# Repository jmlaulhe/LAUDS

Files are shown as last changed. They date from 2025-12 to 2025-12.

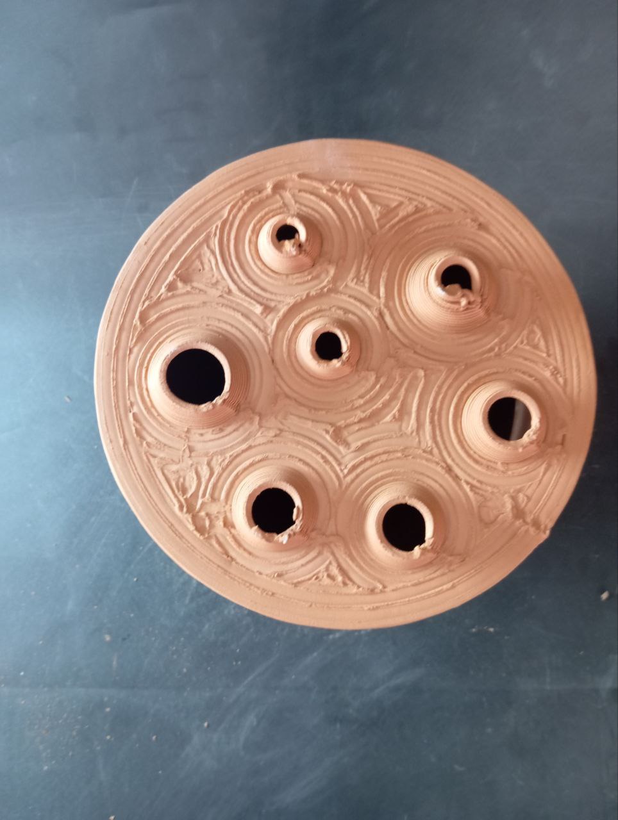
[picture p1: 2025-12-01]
04_hardware/02_sources_media/img/photo_49_2025-10-27_17-47-01.jpg

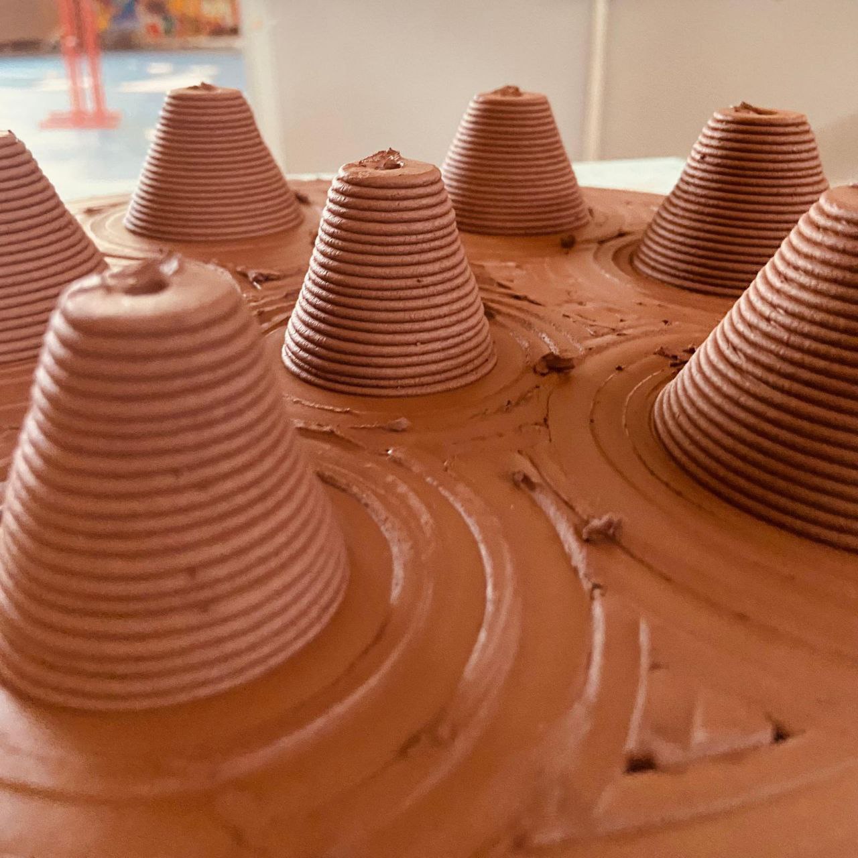
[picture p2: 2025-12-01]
04_hardware/02_sources_media/img/photo_51_2025-10-27_17-47-01.jpg

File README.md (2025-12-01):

# Hacking a plant pot into a vermicomposter

We provide here a guide to hack a plant pot and transform it into a vermicomposter,
a modular system that can be adapted to both vertical and horizontal configurations.

You can also cite and access the project files at:

<https://room11.es/projects/LAUDS-RgitA/>

<https://gardenatlas.net/garden/jardin-acondicionado-1/?filter=2>

## Vision: Vermicomposter for Mediterranean Climates.

We aim to share and improve a functional vermicomposter designed for outdoor environments in Mediterranean climates,
which can be adapted to both vertical and horizontal settings in urban contexts.
The documentation is intended to facilitate the adaptation of the design to different local conditions and to materials that are readily available.

## Metadata

-   development stage: prototype, first stable version of the project, tests ongoing
-   license: CERN-OHL-W for hardware process definitions (content of the 04_hardware folder),  CC BY-SA 4.0 for documentation;.
-   subject area/type of hardware: (vertical) farming
-   prerequisite: documentation made for future contributors

## Main outputs

-   Parametric design files for creating your own vermicomposter by hacking a ceramic plant pot

-   Pictures and guides for adapting the process to different contexts and needs

## Problem description

The lack of fertile soil is common in urban contexts, and its regeneration requires multiple actions.
Vermicomposting is one of the simplest ways to integrate our daily environments into this regenerative process.
Plant pots represent a traditional, widely accepted technology that enhances vermicomposting practices:
they are aesthetically compatible and serve as effective hygrothermal regulators.

## Contributing

Please feel welcome to use the Github issues to flag errors and tell us what you think.
You may also contact the maintainer per email (see contributors section).

## Project history and roadmap

The project builds upon the experience of Gardens in the Air (Nomad Garden, 2021–2023),
a vertical garden implemented on the façade of AES Nuestra Señora de la Candelaria in Seville,
irrigated with condensate water recovered from air-conditioning systems.

The LAUDS framework provided an opportunity to address several constraints
through maker methodologies, participatory prototyping, and open-source design processes.
During the early stages, community feedback from AES Candelaria encouraged us to rethink
the initial vertical-garden concept and explore the integration of the organic carbon cycle
alongside the existing water cycle in the condensate system.

From this reflection emerged a new hypothesis: it is possible to produce fertile soil
within the built environment by embedding vermicomposting systems into both vertical and horizontal structures.
The resulting design — Redesigning Gardens in the Air — aimed to close local material loops
by transforming daily organic waste into humus and reintegrating it into urban cultivation.

The technical challenge lies in adapting this natural process to outdoor, façade-oriented environments,
using bioclimatic ceramic containers capable of buffering temperature fluctuations
through evaporative cooling powered by recovered condensate water.

Next steps:

- Ensure compatibility with other parametric design software

- Open the project for feedback and external contributions

- Test the system in different contexts (urban orchards, community gardens, etc.)

Long term:

-   build a network of vermicomposter initiatives to enable self-managed development of the project

### Related projects

[to be completed]

## Funding

This was developed inside the LAUDS Factories call, facing the challenge "Greening Urban Spaces: Innovate Vertical Farming Systems from Local Waste Streams".

[LAUDS Local Accessible Urban Digital Sustainable Factories](https://www.lauds.eu) is a Horizon Europe research and innovation action - Co-funded by the European Union, 2024-2026, GA 101135986.

## Main contributors:

-   T11- Creative Space
-   Nomad Garden SL
-   Adriano Jiménez
-   Fab Lab Sevilla
-   AES Nuestra Señora de la Candelaria
-   Ecosistema 41

### work culture 

-   [guidelines](01_community/01_community_guidelines.md)
-   [Code of conduct](01_community/02_coc.md)

## Documentation structure

This readme contains the first level of information.
in 
- 01_community are saved our detailed documentation about the community practices
- 02_project_history you will find information about past decisions in the project
- 03_specification_concept you will find high level analysis of the hardware design like the list or requirements and user analysis
- 04_hardware you will find information to build the hardware
- 05_user_guides you will find information to use and maintain/dispose the hardware

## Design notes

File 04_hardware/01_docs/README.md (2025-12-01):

PDF with the main parts of the vermicomposter system to be placed in exteriors

- Shell assembly: recovering the properties of mashrabiya, an Islamic solution for Mediterranean window openings.
- Vermicomposter: parts of the hacking of a plant pot in a vermicomposter.

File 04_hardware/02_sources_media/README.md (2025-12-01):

### Parametric design

Made in Rhinoceros parametric plug-in, Grasshopper.

- Ceramic /PLA lid (Parameters: dimension of rim, geometry, nozzle)
- Trays for the vermicomposter (Parameters: height of trays, dimensions of plant pots, holes for worms)

### CAD drawings

DXF made in AutoCAD for the shell of the mashrabiya.

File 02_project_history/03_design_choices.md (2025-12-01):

**Material Sourcing and Selection**

Primary structural element: traditional fired ceramic pots (15 L) from regional potteries in the Guadalquivir valley. Pots are selected for porosity, dimensional standardisation, and existing supply chains.
Hack components: bespoke lids, capillary distributors, internal trays and seed templates produced by digital fabrication (3D printing in ceramic composite or PLA biocomposite).
Biological input: Eisenia fetida worm communities and local organic residues.

**Design Adaptation and Digital Fabrication**

Parametric design (Rhino + Grasshopper) generates adaptable geometries for retrofitting standard pot sizes. Designs produce: (a) lid inserts that match pot rims; (b) tray geometries that fit pot interior contours; (c) capillary channel patterns for condensate distribution.
Additive fabrication produces the hack components: 3D-printed lids (ceramic composite or clay in lab trials), internal trays (PLA/biocomposite), and small fixtures for anchorage to mashrabiya panels. Where ceramic printing is not feasible, components are printed in PLA biocomposite and later transitioned to fired ceramic versions via collaboration with local kilns.

**Mechanical and Hydraulic Integration (Hacking Traditional Pots)**

The hack operation consists of: (a) preparing the pot rim and interior to receive inserts (minor drilling, chamfering, or application of sealing gaskets where necessary); (b) fitting the custom lid that captures condensate and distributes it across the pot surface through microchannels; (c) installing stackable internal trays that create layered habitats, drainage paths, and aeration.
All modifications are reversible and preserve the integrity of the traditional pot, enabling reusability or return to standard horticultural use.

**Community Assembly and Calibration**

Hacking sessions are organised as participatory workshops with AES Candelaria students and local potters. These sessions include instruction on fitting inserts, maintenance protocols, and simple diagnostic checks (moisture, ventilation, leachate collection).
Performance calibration (moisture rates, worm activity, thermal buffering) is measured in situ and iteratively used to refine both the parametric designs and the installation procedure.

**Closed-Loop Testing and Material Trials**

Produced humus is applied to pot substrates and the association’s urban plots to close the material loop.
Parallel experiments at Fab Lab Sevilla test humus–clay mixtures for future fired components (seed trays, degradable supports), ensuring that any new ceramic parts remain compatible with the traditional pottery supply chain.

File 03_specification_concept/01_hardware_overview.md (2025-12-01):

## foreseen cost (money and time)
The required cost is very low. A 15-liter ceramic pot can range between €15–30 depending on the country.

There is also a non-recurring cost that is useful for activating our vermicomposter: the initial worm colony and some good-quality soil, so that the worms do not suffer when settling in. For around €20 you can obtain a handful of worms (about 500 individuals), and if you wish to purchase humus — which can also be used for your garden — a 40-liter bag costs approximately €20.

Time, however, is a determining factor. At the beginning, you will need to check the vermicomposter almost daily in order to adjust it. Once it is functioning properly, you should tend to it two or three times per week. If there are more extreme temperatures — either hot or cold — you should check it almost every day.

## requirements

## constrains

## capability

## use cases and application

## reuse possibilities

## architectural structure

## Software/firmware architecture

## electrical design architecture

## Component lifetime

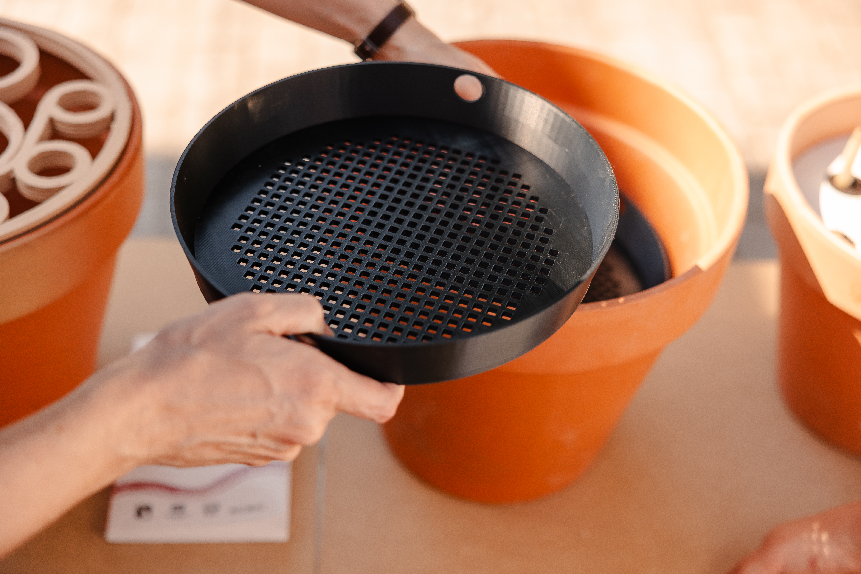
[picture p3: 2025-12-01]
04_hardware/02_sources_media/img/GARDEN ATLAS-AES CANDELARIA-307.jpg

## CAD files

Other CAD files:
04_hardware/02_sources_media/Shell_laser.dxf

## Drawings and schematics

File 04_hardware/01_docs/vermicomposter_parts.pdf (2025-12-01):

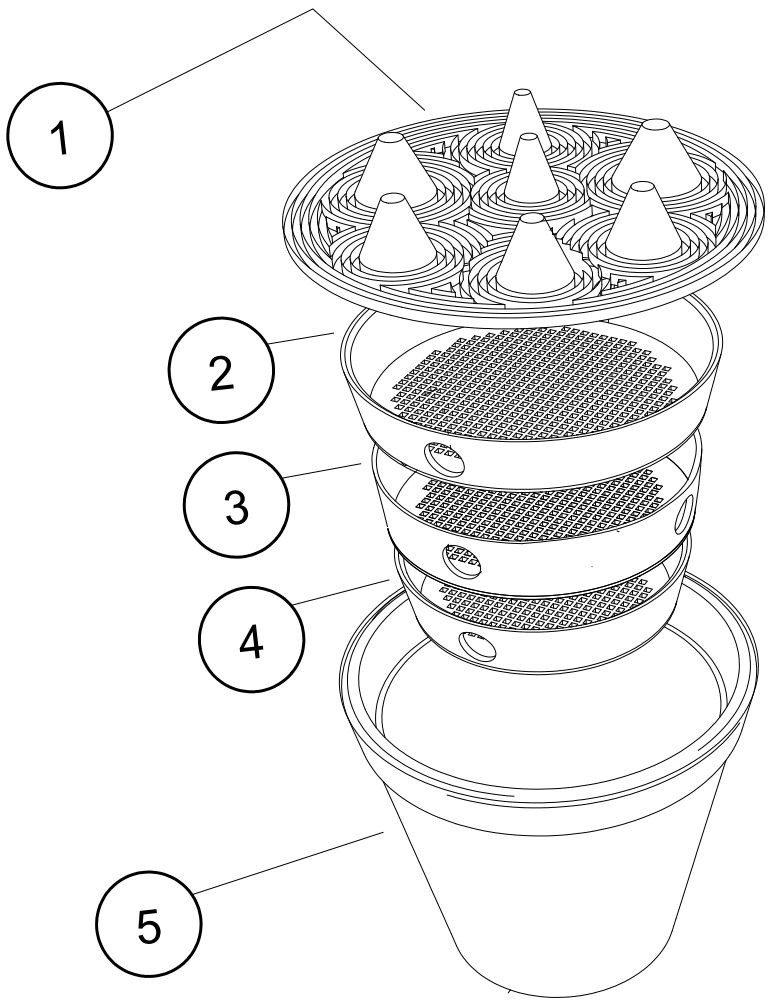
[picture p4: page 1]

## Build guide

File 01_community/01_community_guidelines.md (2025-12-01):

Local suppliers. In our instance, the local potteries (Guadalquivir valley): suppliers of standard ceramic pots and partners for potential fired retrofit parts.

Testing community and space. In our instance, AES Nuestra Señora de la Candelaria: assembly, monitoring and educational partner.

Techincial providers. In our instance, Fab Lab Sevilla & Maker Association: fabrication and prototyping partners for hack components.

Design and coordination. In our instance, Nomad Garden & T11: design coordination, workshop facilitation, and documentation.

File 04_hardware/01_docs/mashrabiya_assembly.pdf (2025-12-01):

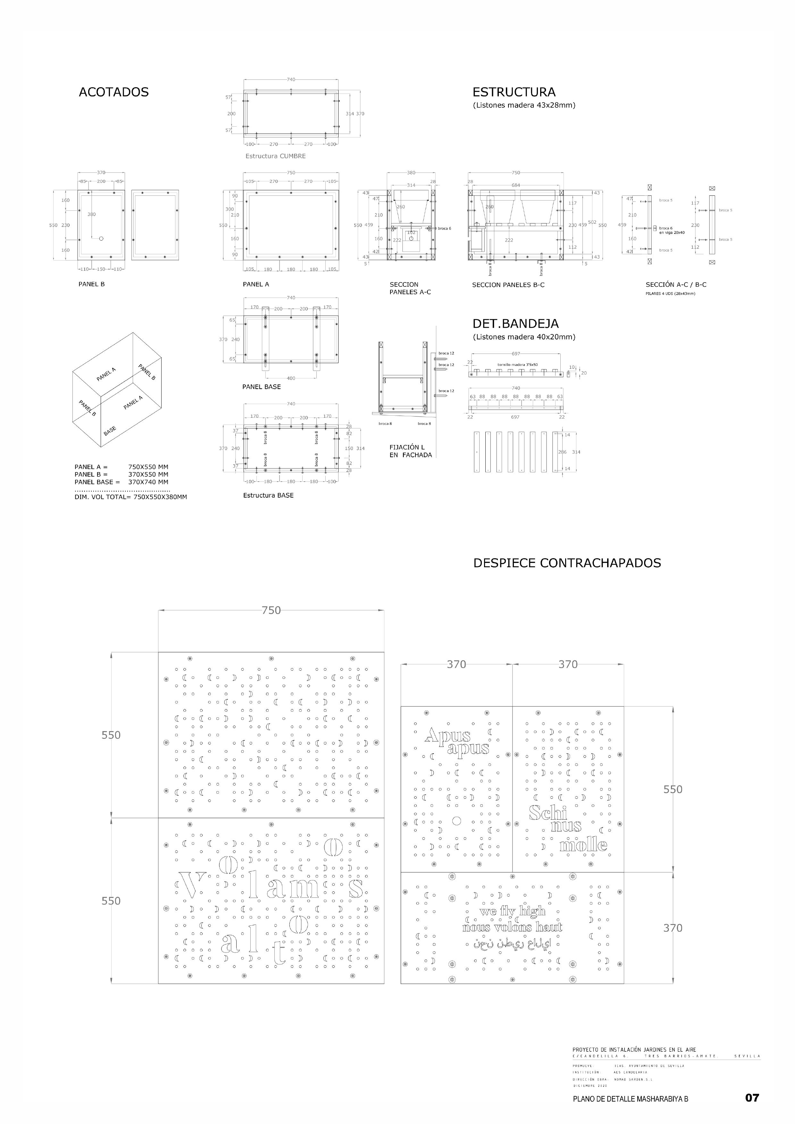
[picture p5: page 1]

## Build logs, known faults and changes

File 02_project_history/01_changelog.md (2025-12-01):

# **Vermicomposter v 1.0:**

Copenhagen - January 2025

Reusing materials of Maker Association Workshop (wood + plastic screw boxes).

Reason: Although there was an existing concern for recycling, there was no protocol for reusing the organic waste generated daily in V-10.

Design based in the set of furniture previously fabricated in V-10.
Responsible: Designers Team.

# **Vermicomposter v 2.0:**

Sevilla - March 2025

Vida XL commercial vermicomposter system + mashrabiya shell.

Reason: Dimensioning adjusted to the needs of the worm community. Emphasis on learning and protection practices around worm care and humus management. Experimental work with humus.

Changes: Main dimensions based in worms morphological requirements (greater horizontal surface and limited depth), integrated in proved vertical system.

Design based in the Gardens in the Air mashrabiya system, adaptable for vertical and horizontal installations.
Responsible: Designers Team.

# **Vermicomposter v 2.1:**

Sevilla - July 2025

Ceramic pots hacked with 3d prints + mashrabiya shell.

Reason: Enhanced resilience to extreme temperatures, enabling evapotranspirative cooling. Improved aesthetic integration of the vermicomposting unit.

Changes: Improved outdoor performance, self-produced design independent of commercial systems, and adaptation to local resources and operational models through parametric design.

Design based in Traditional Ceramic Pot with a hacked lid and stackable trays integrated in the Gardens in the Air mashrabiya system.
Responsible: Designers Team.

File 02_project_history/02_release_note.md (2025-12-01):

Two experimental paths remain under development:

- Worm towers for in-ground applications, which require species capable of deep burrowing (Lumbricus terrestris) rather than surface decomposition (Eisenia foetida).
- 3D printing with humus-based biomaterials, a promising but technically challenging line. Preliminary trials mixing 10–15% humus with clay achieved partial success; higher proportions led to excessive plasticity and oxygen deprivation for living organisms. Future work will focus on formulations optimized for biodegradable seed trays and soil-reintegrable components.
